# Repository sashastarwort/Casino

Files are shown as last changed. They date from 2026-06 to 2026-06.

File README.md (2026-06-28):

# Casino
Опис проєкту
Після натиску кнопки користувачем засвічується перший світлодіод, далі загораються по черзі наступні за годинниковою стрілкою, при засвічуванні обраного світлодіода користувачем він натискає кнопку і запускається режим рулетки: кожен діод загорається почергово спершу пришвидшуючись потім поступово співільнюючи хід і зупиняється на одному. Якщо це був обраний то грає переможна музика, в іншому випадку програшна. Це все супроводжується певним блиманням характерним для кожного з них. Далі користувач при одному натисканні продовжує гру, а при подвійному завершує.
Автор проєкту:
Студентка КПІ ФПСПМ F7 групи КВ-31
Кузьменко Олександра Андріївна

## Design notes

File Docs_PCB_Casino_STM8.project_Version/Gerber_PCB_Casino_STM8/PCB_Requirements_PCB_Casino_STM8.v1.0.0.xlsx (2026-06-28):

PCB Name | PCB_Casino.v1.0 | Template version 1.0.3 | <Parameter PCB_Version not found>
Author | Oleksandra
Amount boards per stand | 1
Produced within | 3 weeks
Item | Requirement | Comment
Layer count | 2
Size | 99.06 x 71.12 mm
Thickness | 1.6 mm
Material | FR-4
Min track/spacing | 0.254mm / 10mil
Min hole size | 0.3 mm
Copper weight | 1oz / 35um
Mask | on both sides
Mask color | Green / White
Castellated holes edges | No
Surfaces finishing | HASL
Silkscreen | YES
Silkscreen color | White
Board Outline, Cutout | Mechanical1 (GM1)
Electric test | Necessarily for 100% samples

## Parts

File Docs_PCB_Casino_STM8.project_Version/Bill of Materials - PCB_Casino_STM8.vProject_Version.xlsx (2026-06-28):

Line # | Name | Description | Designator | Quantity | Manufacturer 1 | Manufacturer Part Number 1 | Manufacturer Lifecycle 1 | Supplier 1 | Supplier Part Number 1 | Supplier Unit Price 1 | Supplier Subtotal 1
 | VS-1213-67-160GF | Button 12*12mm | B1 | 1 | Valcon | VS-1213-67-160GF | Unknown
 | Cap_1206 |  | C1, C2, C3, C5, C7, C9, C10 | 7 | Microchip | CAP1206-1-AIA-TR | Volume Production | DigiKey | CAP1206-1-AIA-TRCT-ND | 0.85 | 5.95
 | Cap_1206 |  | C4, C8 | 2 | Microchip | CAP1206-1-AIA-TR | Volume Production | DigiKey | CAP1206-1-AIA-TRCT-ND | 0.85 | 1.7
 | 100nF |  | C6 | 1 | Cornell Dubilier | 160225K100N-F | Volume Production | DigiKey | 160225K100N-F-ND | 4.56 | 4.56
 | Diode |  | D1, D2, D3, D4, D5, D6, D7, D8, D10, D11, D12, D13, D14 | 13 | Diodes Inc. | LTST-C170AKT | Volume Production | Mouser | 859-LTST-C170AKT | 0.115 | 1.5
 | Diode standart |  | D9 | 1 | Wurth Elektronik | 824500161 | Volume Production | Mouser | 710-824500161 | 0.33 | 0.33
 | USB_Type_C |  | J1 | 1 | Amphenol | 12401832E402A | Volume Production | Newark | 12401832E402A | 0.663 | 0.663
 | Speaker |  | LS1 | 1 | Same Sky | CVS-1508 | Volume Production | Mouser | 490-CVS-1508 | 4.03 | 4.03
 | Conector_4pin |  | P1 | 1 | Molex | 39-29-1047 | Volume Production | Mouser | 538-39-29-1047 | 1.04 | 1.04
 | IRLR2905TRPBF |  | Q1 | 1 | Infineon | IRLR2905TRPBF | Volume Production | Conrad | 3026306 | 0.92705 | 0.92705
 | Res_1206 |  | R1, R3, R5, R6, R7, R8, R9, R10, R13, R15, R16, R17 | 12
 | Res_1206 |  | R2, R4 | 2
 | Res_1206 |  | R11, R18 | 2
 | Res_1206 |  | R12 | 1
 | Res_1206 |  | R14 | 1
 | Res_1206 |  | R19 | 1
 | Res_1206 |  | R20, R21 | 2
 | SN74HC595N |  | U1, U3 | 2 | Texas Instruments | SN74HC595N | Volume Production | Newark | SN74HC595N | 1.69 | 3.38
 | CH340С |  | U2 | 1
 | USBLC6-2SC6 |  | U4 | 1 | STMicroelectronics | USBLC6-2SC6 | Volume Production | Conrad | 3409272 | 0.15065 | 0.15065
 | STM8S103F3P6 |  | U5 | 1 | STMicroelectronics | STM8S103F3P6 | Volume Production | Avnet | 16AC3543 | 0.94 | 0.94

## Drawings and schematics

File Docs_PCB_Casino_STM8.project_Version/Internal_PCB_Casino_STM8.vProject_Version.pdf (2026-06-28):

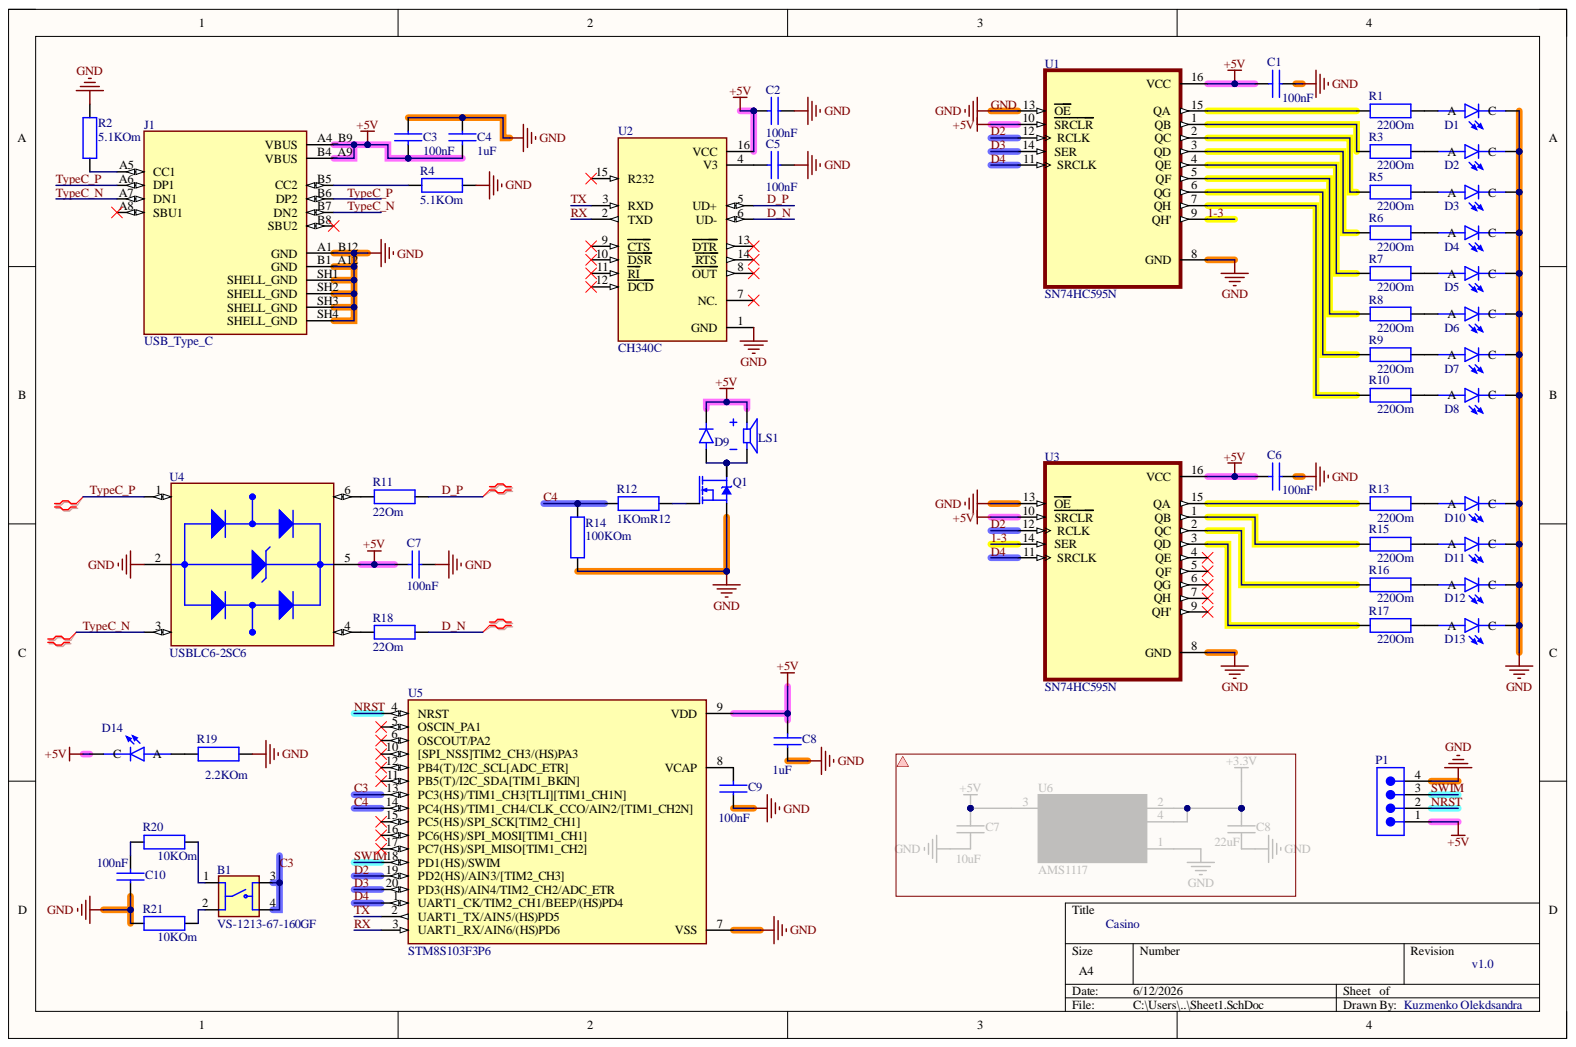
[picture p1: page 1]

7 | | D 3A
9 | 1-3

Da te : 6/12/202 6 | She et of
File : C:\Use rs\. .\She et1 . S c hD o c | Dr awn B y : Kuzmenko Olekdsa n dr a

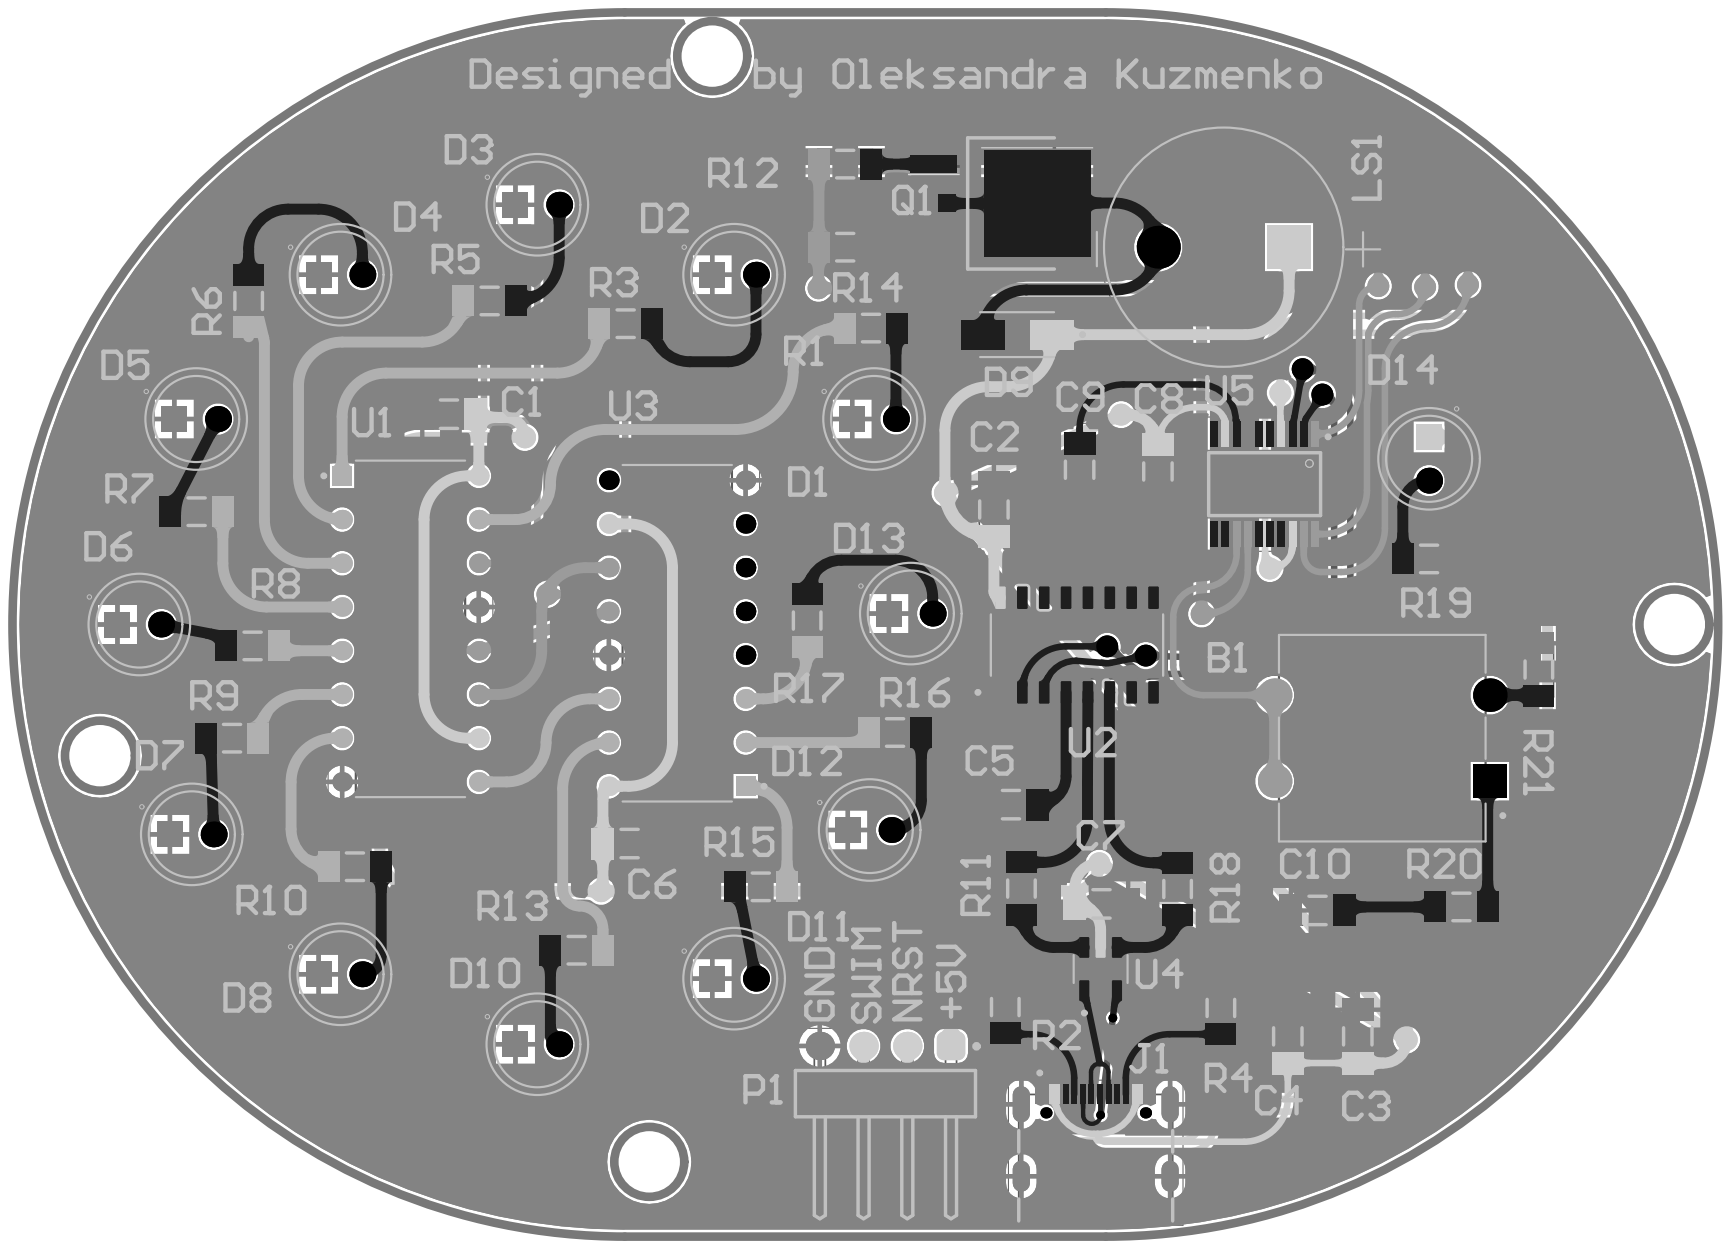
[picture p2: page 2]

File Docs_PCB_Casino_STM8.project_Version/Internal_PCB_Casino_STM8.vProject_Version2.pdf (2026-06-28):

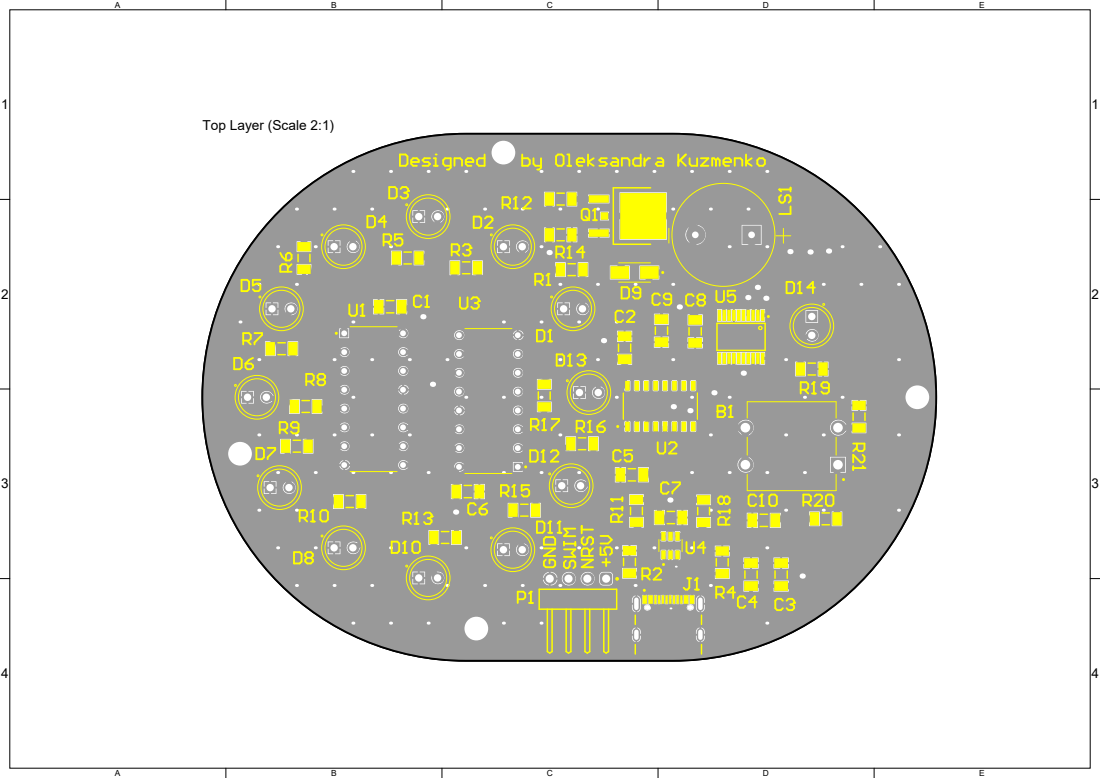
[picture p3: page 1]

Top Layer (Scale 2:1)

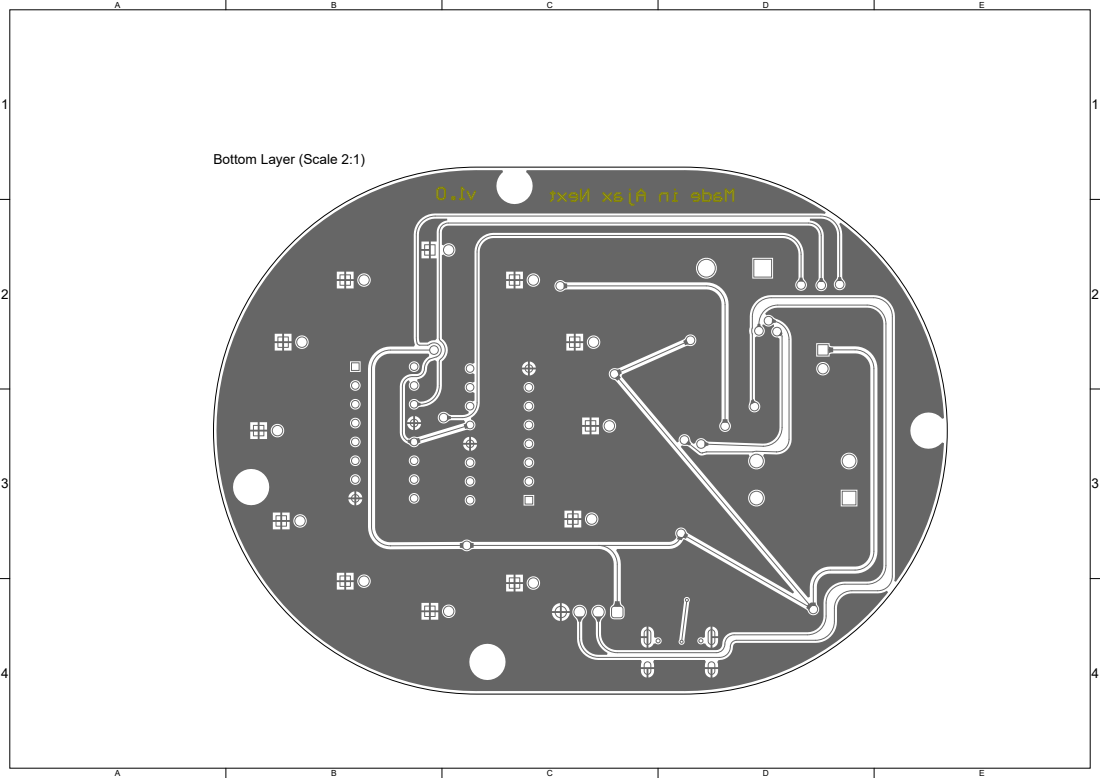
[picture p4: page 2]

Bottom Layer (Scale 2:1)

1 | 1
4 | 4

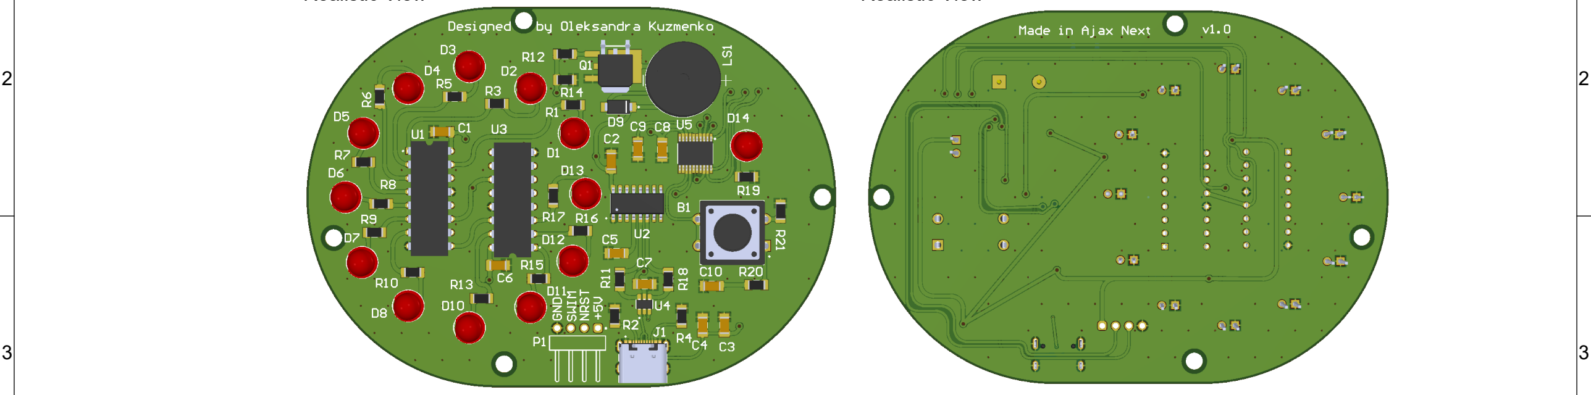
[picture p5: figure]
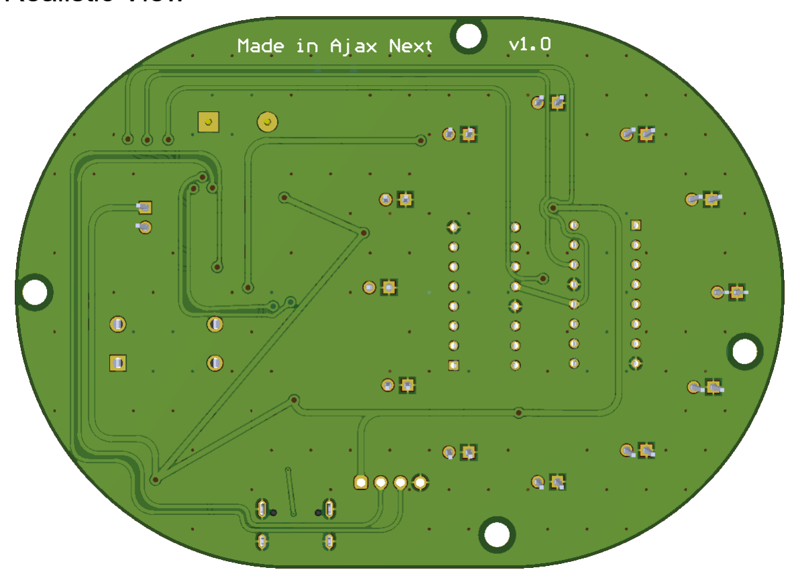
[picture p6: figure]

Realistic View | Realistic View

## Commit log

2025-09-10 add project
    [Casino.PrjPcb, Sheet1.SchDoc]
2026-06-01 Clean project
    [Casino.PrjPcb, Sheet1.SchDoc]
2026-06-11 Add polyhon and check
    [Casino.PrjPcb, PCB1.PcbDoc]
2026-06-15 ADD Gerber files + documentation
    [Casino.PrjPcb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]
2026-06-28 ADD fikes
    [Bill of Materials - PCB_Casino_STM8.vProject_Version.xlsx, Casino.PrjPcb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]
